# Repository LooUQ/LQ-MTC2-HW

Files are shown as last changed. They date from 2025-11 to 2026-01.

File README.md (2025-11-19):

# LooUQ MTC.2 Hardware

Welcome to the hardware and physical parts repository for the LooUQ MTC.2 Ecosystem. Here you will find resources to aid in your implementation of MTC.2 devices in your design/product. Many parts of the LooUQ MTC.2 ecosystem are available as open-source hardware and there design files are available here. There are also drawings for components that can be 3D printed. 

Software developement tooling is found in the LQ-MTC2-SW repository, which is also found on LooUQ's GitHub site.

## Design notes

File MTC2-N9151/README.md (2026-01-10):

# LooUQ MTC2-N9151

The LooUQ MTC2-N9151 is our flagship modem based on the Nordic Semiconductor nRF9151 System-in-Package (SIP) device. Nordic's [documentation](https://docs.nordicsemi.com/category/nrf9151-category) about the nRF9151 SIP is relevant the our MTC2-N9151 modem. LooUQ has done the work to package the nRF9151 SIP into a convenient PCB form to make incorporation into your device as straight forward as possible.

The [MTC.2 Interface Guide](https://drive.google.com/file/d/1XxZAA_1KvOwKZDBlQWn0SYPFL24nAV9U/view?usp=drive_link) discusses the steps to incorporate the N9151 into your product/project. 
* The physical characteristics of mounting the N9151 in your host system
* The electrical requirements needed by the N9151
* The signals to/from the N9151 and it's host

*LooUQ software developement tooling is found in the [LQ-MTC2-SW](https://github.com/LooUQ/LooUQ-MTC2-SW) repository (also found on LooUQ's GitHub site). This includes resources for Nordic Connect SDK like board definition files and sample applications.*

# What You Need
To work with the MTC2-N9151 you will need some things at hand.
* Microsoft [Visual Studio Code](https://code.visualstudio.com/) code editor
* Nordic's [Nordic NRF Connect](https://www.nordicsemi.com/Products/Development-tools/nRF-Connect-for-Desktop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) extension for VS Code
* Nordic's [nRF Connect for Desktop](https://www.nordicsemi.com/Products/Development-tools/nRF-Connect-for-Desktop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) (optional, but highly recommended)
* A SWD debugging probe (Segger J-Link recommended)
* A MTC.2 host providing connections and power (see LooUQ's offerings below, available in our online store)
* A MTC2-N9151 *(of course you will need one or more of these)*
* Antenna(s) 
    * Depending on your use case you will need a cellular antenna for LTE/DECT-NR+ and a GNSS antenna for GNSS/GPS location determination.

## Using LooUQ Development hosts
LooUQ has two development hosts available to make getting started with the MTC2-N9151 a straight forward process: the MTC2-N9151-BRK (breakout board) and the MTC2-N9151-UXP (UXplor host). With either of these two boards, you can get started developing applications for the N9151. They are physically the same size and have identical peripheral header pin configurations.

### MTC2-N9151-Breakout
The N9151 breakout board is simply that, a breakout, exposing all the signals to/from the MTC2-N9151 modem device. Connections for external power, nRF9151 reset, SWD (flash/debug) and all peripheral pins (GPIO, I2C, SPI, UART, etc.). The breakout is designed to be simple and stay out of the way, providing only the essentials for flashing and debugging your N9151 applications.

### MTC2-N9151-UXplor
The N9151 UXplor is the breakout PLUS handy other functionality. The UXplor has a USB connector that sources power via integrated regulators. There is a VDD regulator delivery 3.8v and a VIO regulator that can be set for 3.3v or 1.8v. There is also a RGB LED indicator, the RBG controller is from TI and is I2C-connected. LooUQ provides a driver for LED controller, which is available in the LooUQ-MTC2-SW software repository.

## Creating MTC2-N9151 Applications
If you are new to ***Nordic nRF Connect*** consider investing time in completing one or more of the fine online courses at the [Nordic Developer Academy](https://academy.nordicsemi.com/). If you already have nRF Connect development experience, head over to the [software repository](https://github.com/LooUQ/LooUQ-MTC2-SW) and check out the information there. We have board definitions, samples, and driver code ready for your use. 

## Creating Your Own MTC2-N9151 Host 
LooUQ uses DipTrace as our PCB design suite. It has a complete set of tools for schematic creation, PCB layout, and maintaining component libraries. For information about DipTrace and how to use it see...[Get Diptrace](https://diptrace.com/). LooUQ has been using DipTrace as our electronics design tool since 2016 and we are proud to proclaim it's virtues: reasonable cost, wide support, comprehensive set of tooling; give it a try.

Given that there are multiple tools out there for PCB design/develoment, LooUQ is sharing our open-hardware designs in both DipTrace and Eagle formats. Eagle is a widely supported format for schematic and PCB board layouts. Both of the host boards above are available in the Boards folder of this repository. Depending on your needs either could be a good starting point for integration into your project.

Nordic documentation about the nRF9151 SIP applies to the LooUQ MTC2-9151; all limits should be observed. The MTC2-N9151 will draw slightly more power depending on operating state. GNSS has power draw for either the on-board LNA chip and optionally the external LNA power injection circuit. The N9151 also has 2 LEDs (power-green, network-blue), which can be individually disabled by cutting a jumper. LooUQ can deliver the MTC2-N9151 with custom LNA or LED configurations (note MOQ is required).

### Interfacing to the N9151
* Physical layout
* Power
    * VDD: 3.0v - 5.5v (LooUQ has observed that when VDD is above 4.5v, a VIO of 1.8v has issues)
    * VIO: 1.7v to 3.6v
    * The UXplor VDD is 3.8v and VIO is selectable at 3.3v or 1.8v
* Flash/debug requires connectivity to the 2 SWD pins (both the Breakout and UXplor expose these signals to a 10-pin Cortex header)
* Both LTE/DECT and GNSS antennas are directly connected to the MTC2-N9151 via U.FL connectors

**Host Physical Board Layout**
The physical connection between the MTC2-N9151 and the host PCB is accomplished with 3 parts in the configuration below.
* TE 1-2199230-6 (M.2 Key-M)
* Wurth 9774025151R (M2.5 stand-off, soldered)
* 2.5M x 8mm hex head bolt (fully-threaded, course)

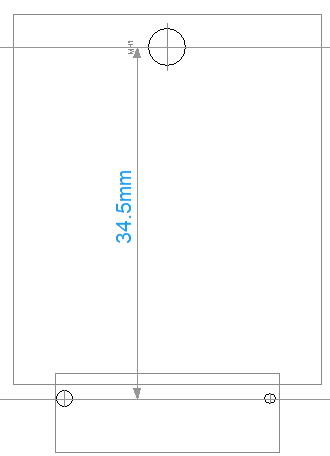
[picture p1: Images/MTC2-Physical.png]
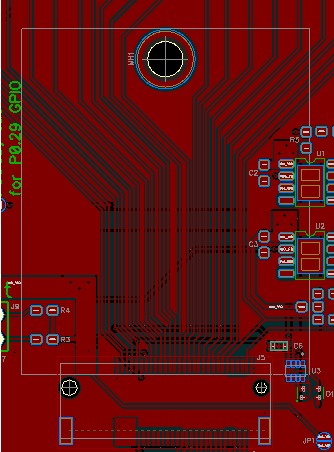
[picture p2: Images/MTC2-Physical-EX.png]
PCB


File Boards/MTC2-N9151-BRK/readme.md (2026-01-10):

# MTC2-N9151-BRK
The LooUQ MTC2-N9151 Breakout is a development board providing pin access to all of the MTC2-N9151 signals. It allows for software development, flashing and power monitoring via headers located along the right-hand side of the board. SWD access (debug/flashing) is via a standard 5x2 shrouded header.

The Breakout can also serve as a template for incorporating the MTC2-N9151 modem into your product design. Both DipTrace and Eagle design files are available here.

You can purchase ready-to-use Breakout boards from LooUQ at https://loouq.com/store.

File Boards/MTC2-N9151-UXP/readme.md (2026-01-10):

# MTC2-N9151-UXP
The LooUQ MTC2-N9151 UXplor is a development board providing pin access to all of the MTC2-N9151 signals. It allows for software development, flashing and power monitoring via headers located along the right-hand side of the board. SWD access (debug/flashing) is via a standard 5x2 shrouded header. The UXplor also provide N9151 board power from a USB connection. The VIO voltage can be selected via a jumper at either 3.3v or 1.8v (VDD is fixed at 3.7v). The UXplor also includes a RGB LED the is controlled via a TI constant current control chip on the host extension I2C interface.

You can obtain Zephyr devicetree overlays for the Host Extension interface in order to use the RGB LED with the LooUQ driver. These resources, including the driver, are found in the LooUQ GitHub at https://github.com/LooUQ/LooUQ-MTC2-SW.

You can purchase ready-to-use UXplor boards from LooUQ at https://loouq.com/store.

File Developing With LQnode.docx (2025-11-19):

# Developing With LQnode

Developing your sensor or actuator project with LQnode is a straightforward effort involving both creation of a “sensor” circuit and adding your C source code driver. Both efforts are supported by templates to facilitate a solid start and rapid completion.

# Hardware Circuit

## PCB Design Software

LQnode includes hardware templates and source materials to help you rapidly build your project. LooUQ provides these design resources (schematics and PC boards) in two formats: DipTrace and Eagle.

LooUQ uses DipTrace as our primary circuit CAD application. We selected it several years ago and have been pleased with its reasonable cost and solid features. DipTrace is available

Part of most LQnode projects is a custom circuit board (PCB) that is home to the electronics that make your sensor project unique; this could be actual sensors or more likely interface(s) to an external device or system. Beyond the interface itself, your hardware could also include specialized processing capabilities such as high-end computation power, extra memory, or a field programmable gate array (FPGA). This allows your project to utilize the LQnode platform for power and communications, while you focus on your core expertise to address a real-world need.

Start your hardware development with the LQnode-ANNEX PCB template. The template is available as a DipTrace or Eagle format board (https://github.com/LooUQ/LQnode-HW). The template has a board outline, connectors to the LQnode system board, and a placeholder group of prototyping pads. The prototyping connections can be kept or deleted as you see fit.

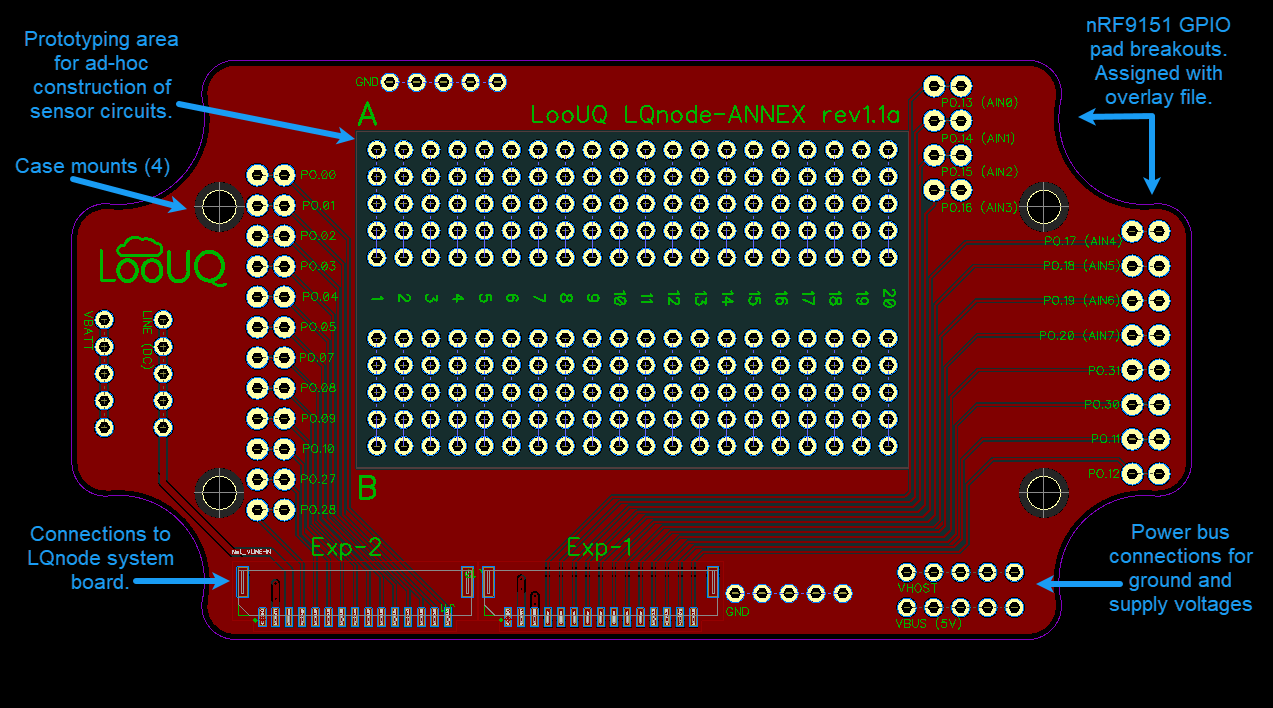
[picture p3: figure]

The only part on the prototype template PCB that is required are the two connectors to the LQnode system board. These are common JST BM15B-GHS-TBT(LF)(SN) connectors, you will also find compatible cables and plugs available from multiple sources. This connector has a latch mechanism to lock the connection cable in place.

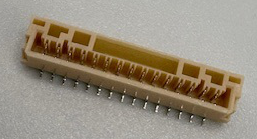
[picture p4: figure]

# Software Driver

As with hardware development, the best starting point is the LooUQ provided LQnode application template. LQnode software support files including demo applications/ templates and overlays, Zephyr port mappings for Nordic Connect SDK, are available in the https://github.com/LooUQ/LQnode-SW GitHub repository.

# Licensing

LooUQ has expended time and money developing the LQnode system for rapid development of IoT device applications. We want its capabilities to be put to work addressing real world needs both for good of all and for profit.

All LQnode components, hardware and software, are available under the Polyform Noncommercial (https://polyformproject.org/licenses/noncommercial/1.0.0/) license for non-commercial projects. Polyform Noncommercial is a source-available license, rather than an open-source license. The full source code and component drawings are available for your use, under the license conditions.

Individuals, academic institutions, and non-profit organizations are encouraged to freely use the LQnode system for your project.

Commercial use of LQnode requires a commercial use license that can be obtained from LooUQ. To inquire about pricing and availability of a license compatible with your project please reach out, we are eager to work with you to provide reasonable terms. Licensing inquiries can be directed to answers@loouq.com, we will respond as soon as possible to start working on ways we can work together for mutual benefit.

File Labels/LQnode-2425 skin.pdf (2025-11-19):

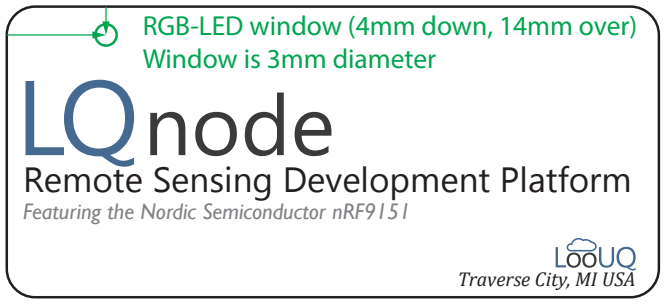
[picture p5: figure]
node; Remote Sensing Development Platform; Traverse City, MI USA; Featuring the Nordic Semiconductor nRF9151; RGB-LED window (4mm down, 14mm over) Window is 3mm diameter

Die-cut outline above: 92mm x 41mm, 4mm rounded corners

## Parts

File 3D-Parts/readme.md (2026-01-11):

## LQnode 3D Printable Parts

This folder contains STL files for enclosure accessories. The parts here are all available open-source, so print away. They also 
can be purchased from the LooUQ Store if that is more convenient [LQstore](https://loouq.com/store).

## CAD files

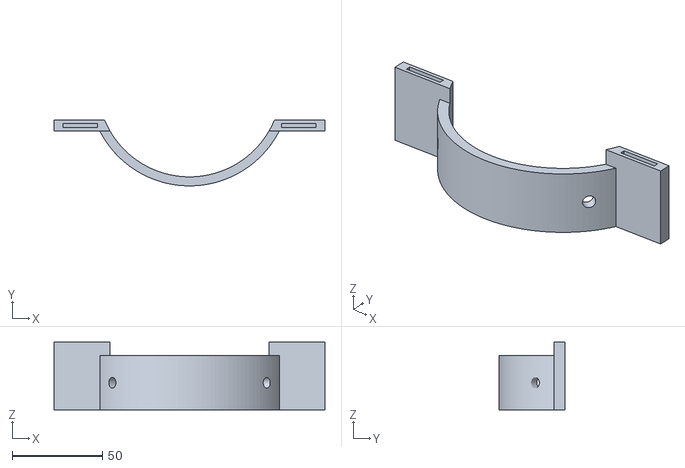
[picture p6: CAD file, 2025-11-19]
3D-Parts/lqnode_ventAdptr4.stl
150.0 x 36.4 x 37.5

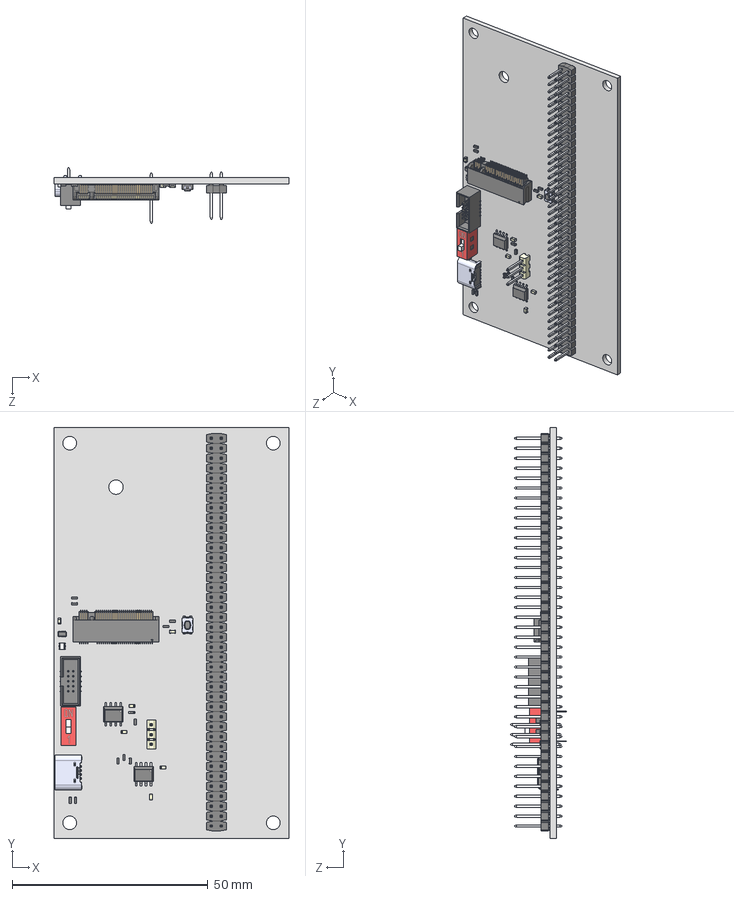
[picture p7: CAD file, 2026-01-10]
Boards/MTC2-N9151-UXP/MTC2-N9151-UXP rev2-2a.step
60.0 x 105.0 x 14.2 mm
Board_mtc2-n9151-uxplor_rev2-2a
cap_0603 x 5
CL10B105KP8NNNC
Everlight--EAST1616RGBB4
CNC-3220-10-0300-00
TE_1-2199230-6
GCT__USB4125-GF-A-0190
hdr-2x40t_2.54x2.54_102x5
hdr-1x3t_2.54_7x2
res_0603 x 11
C&K-KMR231GLFS
Wurth_418117270901
soic-8ep_150mil x 2
TI--LP5817DRLR

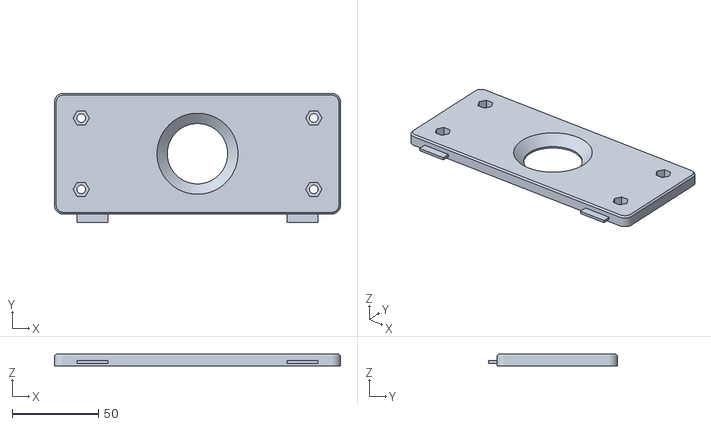
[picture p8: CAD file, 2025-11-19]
3D-Parts/lqnode_backPlate.stl
166.0 x 75.0 x 7.00

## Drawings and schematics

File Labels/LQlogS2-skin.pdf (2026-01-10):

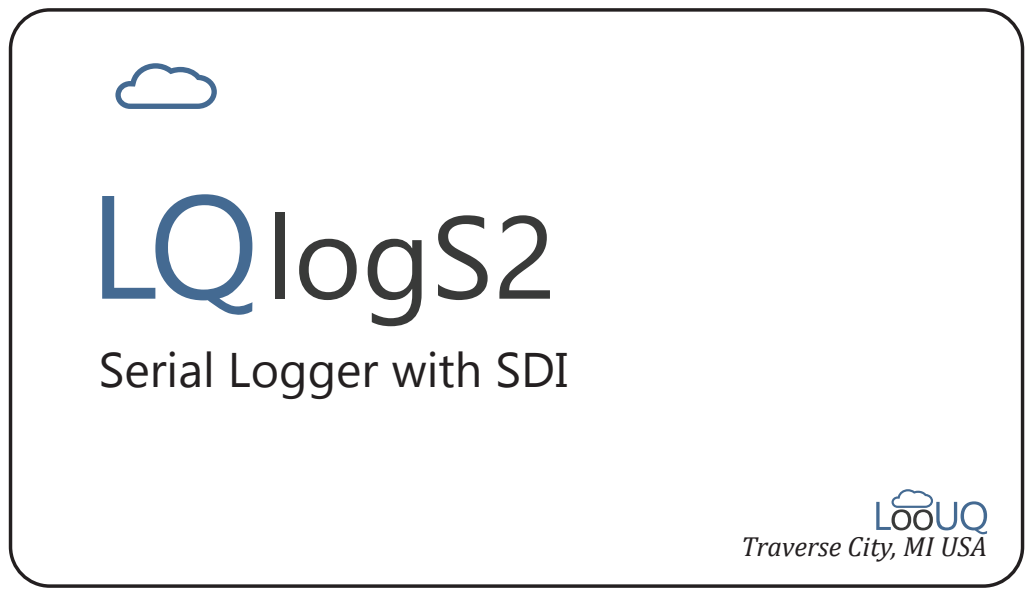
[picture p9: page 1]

RGB-LED window (8.1mm down, 15.4mm over)
Window is 3mm diameter
logS2

Serial Logger with SDI

Traverse City, MI USA

Die-cut outline above: 103mm x 58mm, 4mm rounded corners

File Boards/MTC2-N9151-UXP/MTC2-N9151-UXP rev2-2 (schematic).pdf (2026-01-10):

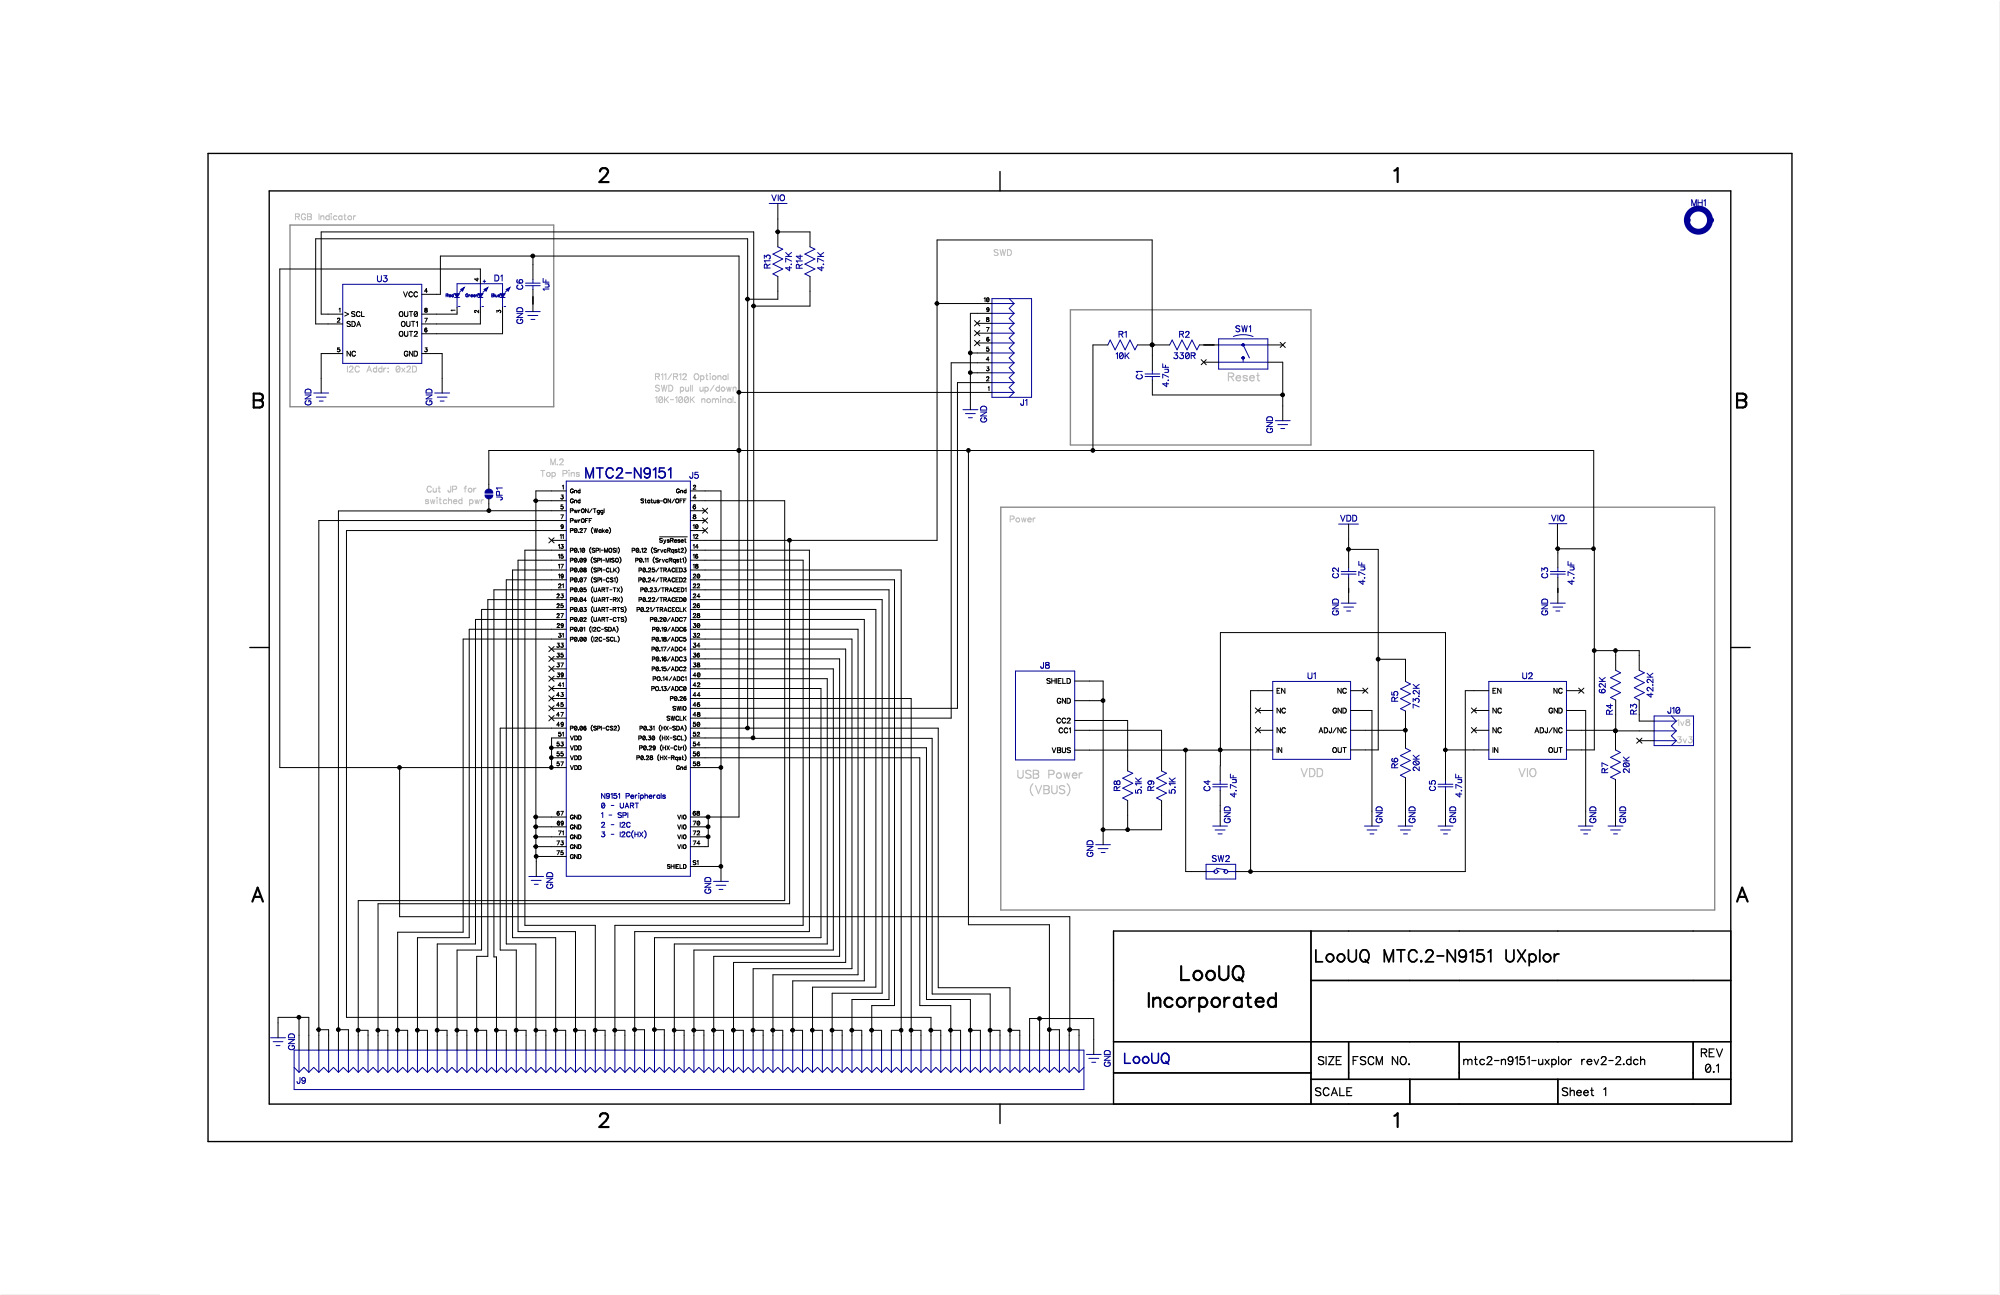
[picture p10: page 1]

R11/R12 Optional
SWD pull up/down
10K-100K nominal.

PwrON/Tggl 5 | 6
PwrOFF 7 | 8
9 | | 10
11 | | 14 16 18 20 22 24 28 30 32 34

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
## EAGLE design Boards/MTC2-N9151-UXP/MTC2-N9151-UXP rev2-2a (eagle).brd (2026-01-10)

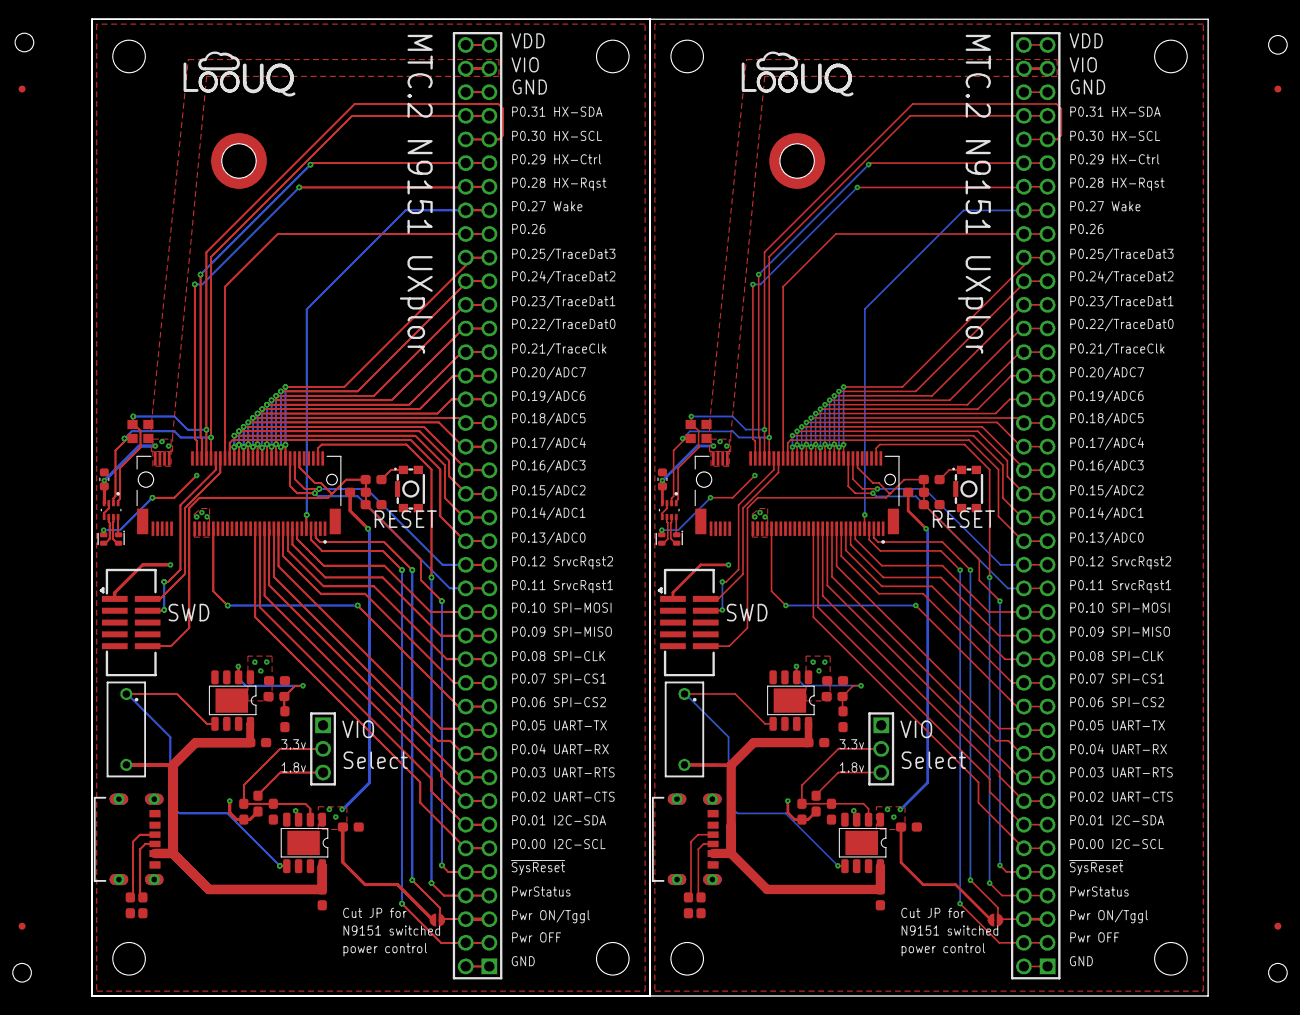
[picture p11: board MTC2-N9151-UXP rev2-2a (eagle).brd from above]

Board: 2 copper layers, 120.0 x 105.0 mm, 66 parts (0 on the bottom side), 52 nets.

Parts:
C1_1_1, C1_2_1, C2_1_1, C2_2_1, C3_1_1, C3_2_1, C4_1_1, C4_2_1: 4.7uF; CAP_0603
C5_1_1, C5_2_1: 4.7uF; CAP_0603_C5
C6_1_1, C6_2_1: 1uF; CAP_0603_N
D1_1_1, D1_2_1: EAST1616RGBB4; EAST1616RGBB2
FID1, FID2, FID3, FID4: FIDUCIAL; Fiducial
J1_1_1, J1_2_1: CNCTECH 3220-10-0300-00-TR; CnCTech_3220-10-0300-00-TR
J5_1_1, J5_2_1: MTC.2 1-2199230-6 (N9151); TE_1-2199230-6
J8_1_1, J8_2_1: USB4125-GF-A-0190; GCT_USB4125-GF-A-0190_REVA2
J9_1_1, J9_2_1: 90131-0160; HDR-2x40T/2.54x2.54/102x5
J10_1_1, J10_2_1: HDR-1X3T/2.54; HDR-1x3T/2.54/7x2
JP1_1_1, JP1_2_1: CIRCJUMPER-2; Circ-Jumper-2
LG1_1_1, LG1_2_1: LOOUQ LOGO; LooUQ-6mm
MH1_1_1, MH1_2_1: 9774025151R; m.2_standoff
R1_1_1, R1_2_1: 10K; RES_0603
R2_1_1, R2_2_1: 330R; RES_0603_R2
R3_1_1, R3_2_1: 41.7K; RES_0603_R3
R4_1_1, R4_2_1: 62K; RES_0603_R2
R5_1_1, R5_2_1: 73.2K; RES_0603_R5
R6_1_1, R6_2_1: 20K; RES_0603_R6
R7_1_1, R7_2_1: 20K; RES_0603_R5
R8_1_1, R8_2_1, R9_1_1, R9_2_1: 5.1K; RES_0603_R8
R13_1_1, R13_2_1, R14_1_1, R14_2_1: 4.7K; RES_0603_R13
SW1_1_1, SW1_2_1: KMR221GLFS; KMR-2-wG
SW2_1_1, SW2_2_1: 418117270901
U1_1_1, U1_2_1, U2_1_1, U2_2_1: AP7361EA-SPR-13; SO-8EP
U3_1_1, U3_2_1: LP5817DRLR; IC_LP5817DRLR

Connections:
ND_RESETSW: R2_1_1.2, R2_2_1.2, SW1_1_1.1@, SW1_1_1.1@_1, SW1_2_1.1@, SW1_2_1.1@_1
Net_52: J10_1_1.3, J10_2_1.3, R3_1_1.1, R3_2_1.1
Net_Blue: D1_1_1.3, D1_2_1.3, U3_1_1.6, U3_2_1.6
Net_GND: C1_1_1.1, C1_2_1.1, C2_1_1.1, C2_2_1.1, C3_1_1.1, C3_2_1.1, C4_1_1.1, C4_2_1.1, C5_1_1.1, C5_2_1.1, C6_1_1.1, C6_2_1.1, J1_1_1.3, J1_1_1.5, J1_1_1.9, J1_2_1.3, J1_2_1.5, J1_2_1.9, J5_1_1.1, J5_1_1.2, J5_1_1.3, J5_1_1.58, J5_1_1.67, J5_1_1.69, J5_1_1.71, J5_1_1.73, J5_1_1.75, J5_1_1.S1, J5_1_1.S2, J5_2_1.1, J5_2_1.2, J5_2_1.3, J5_2_1.58, J5_2_1.67, J5_2_1.69, J5_2_1.71, J5_2_1.73, J5_2_1.75, J5_2_1.S1, J5_2_1.S2, J8_1_1.A12, J8_1_1.S1, J8_1_1.S2, J8_1_1.S3, J8_1_1.S4, J8_2_1.A12, J8_2_1.S1, J8_2_1.S2, J8_2_1.S3, J8_2_1.S4, J9_1_1.1, J9_1_1.2, J9_1_1.75, J9_1_1.76, J9_2_1.1, J9_2_1.2, J9_2_1.75, J9_2_1.76, R6_1_1.2, R6_2_1.2, R7_1_1.1, R7_2_1.1, R8_1_1.1, R8_2_1.1, R9_1_1.1, R9_2_1.1, SW1_1_1.2@, SW1_1_1.2@_1, SW1_2_1.2@, SW1_2_1.2@_1, U1_1_1.3, U1_2_1.3, U2_1_1.3, U2_2_1.3, U3_1_1.3, U3_1_1.5, U3_2_1.3, U3_2_1.5
Net_Green: D1_1_1.2, D1_2_1.2, U3_1_1.7, U3_2_1.7
Net_PWR-TGL: J5_1_1.5, J5_2_1.5, J9_1_1.5, J9_1_1.6, J9_2_1.5, J9_2_1.6, JP1_1_1.1, JP1_2_1.1
Net_PwrEn: SW2_1_1.1, SW2_2_1.1, U1_1_1.5, U1_2_1.5, U2_1_1.5, U2_2_1.5
Net_Red: D1_1_1.1, D1_2_1.1, U3_1_1.8, U3_2_1.8
Net_SWCLK: J1_1_1.4, J1_2_1.4, J5_1_1.48, J5_2_1.48
Net_SWIO: J1_1_1.2, J1_2_1.2, J5_1_1.46, J5_2_1.46
Net_VBUS: C4_1_1.2, C4_2_1.2, C5_1_1.2, C5_2_1.2, J8_1_1.A9, J8_2_1.A9, SW2_1_1.A1, SW2_2_1.A1, U1_1_1.8, U1_2_1.8, U2_1_1.8, U2_2_1.8
Net_VDD: C2_1_1.2, C2_2_1.2, D1_1_1.4, D1_2_1.4, J5_1_1.51, J5_1_1.53, J5_1_1.55, J5_1_1.57, J5_2_1.51, J5_2_1.53, J5_2_1.55, J5_2_1.57, J9_1_1.79, J9_1_1.80, J9_2_1.79, J9_2_1.80, R5_1_1.2, R5_2_1.2, U1_1_1.1, U1_2_1.1
Net_VIO: C3_1_1.2, C3_2_1.2, C6_1_1.2, C6_2_1.2, J1_1_1.1, J1_2_1.1, J5_1_1.68, J5_1_1.70, J5_1_1.72, J5_1_1.74, J5_2_1.68, J5_2_1.70, J5_2_1.72, J5_2_1.74, J9_1_1.77, J9_1_1.78, J9_2_1.77, J9_2_1.78, JP1_1_1.2, JP1_2_1.2, R1_1_1.2, R1_2_1.2, R3_1_1.2, R3_2_1.2, R4_1_1.2, R4_2_1.2, R13_1_1.2, R13_2_1.2, R14_1_1.2, R14_2_1.2, U2_1_1.1, U2_2_1.1, U3_1_1.4, U3_2_1.4
P0.01_(I2C-SCL): J5_1_1.31, J5_2_1.31, J9_1_1.11, J9_1_1.12, J9_2_1.11, J9_2_1.12
P0.01_(I2C-SDA): J5_1_1.29, J5_2_1.29, J9_1_1.13, J9_1_1.14, J9_2_1.13, J9_2_1.14
P0.02_(UART-CTS): J5_1_1.27, J5_2_1.27, J9_1_1.15, J9_1_1.16, J9_2_1.15, J9_2_1.16
P0.03_(UART-RTS): J5_1_1.25, J5_2_1.25, J9_1_1.17, J9_1_1.18, J9_2_1.17, J9_2_1.18
P0.04_(UART-RX): J5_1_1.23, J5_2_1.23, J9_1_1.19, J9_1_1.20, J9_2_1.19, J9_2_1.20
P0.05_(UART-TX): J5_1_1.21, J5_2_1.21, J9_1_1.21, J9_1_1.22, J9_2_1.21, J9_2_1.22
P0.06_(SPI-CS2): J5_1_1.49, J5_2_1.49, J9_1_1.23, J9_1_1.24, J9_2_1.23, J9_2_1.24
P0.07_(SPI-CS1): J5_1_1.19, J5_2_1.19, J9_1_1.25, J9_1_1.26, J9_2_1.25, J9_2_1.26
P0.08_(SPI-CLK): J5_1_1.17, J5_2_1.17, J9_1_1.27, J9_1_1.28, J9_2_1.27, J9_2_1.28
P0.09_(SPI-MISO): J5_1_1.15, J5_2_1.15, J9_1_1.29, J9_1_1.30, J9_2_1.29, J9_2_1.30
P0.10_(SPI-MOSI): J5_1_1.13, J5_2_1.13, J9_1_1.31, J9_1_1.32, J9_2_1.31, J9_2_1.32
P0.11_(nSrvcRqst1): J5_1_1.16, J5_2_1.16, J9_1_1.33, J9_1_1.34, J9_2_1.33, J9_2_1.34
P0.12_(nSrvcRqst2): J5_1_1.14, J5_2_1.14, J9_1_1.35, J9_1_1.36, J9_2_1.35, J9_2_1.36
P0.13/ADC0: J5_1_1.42, J5_2_1.42, J9_1_1.37, J9_1_1.38, J9_2_1.37, J9_2_1.38
P0.14/ADC1: J5_1_1.40, J5_2_1.40, J9_1_1.39, J9_1_1.40, J9_2_1.39, J9_2_1.40
P0.15/ADC2: J5_1_1.38, J5_2_1.38, J9_1_1.41, J9_1_1.42, J9_2_1.41, J9_2_1.42
P0.16/ADC3: J5_1_1.36, J5_2_1.36, J9_1_1.43, J9_1_1.44, J9_2_1.43, J9_2_1.44
P0.17/ADC4: J5_1_1.34, J5_2_1.34, J9_1_1.45, J9_1_1.46, J9_2_1.45, J9_2_1.46
P0.18/ADC5: J5_1_1.32, J5_2_1.32, J9_1_1.47, J9_1_1.48, J9_2_1.47, J9_2_1.48
P0.19/ADC6: J5_1_1.30, J5_2_1.30, J9_1_1.49, J9_1_1.50, J9_2_1.49, J9_2_1.50
P0.20/ADC7: J5_1_1.28, J5_2_1.28, J9_1_1.51, J9_1_1.52, J9_2_1.51, J9_2_1.52
P0.21/TRACECLK: J5_1_1.26, J5_2_1.26, J9_1_1.53, J9_1_1.54, J9_2_1.53, J9_2_1.54
P0.22/TRACED0: J5_1_1.24, J5_2_1.24, J9_1_1.55, J9_1_1.56, J9_2_1.55, J9_2_1.56
P0.23/TRACED1: J5_1_1.22, J5_2_1.22, J9_1_1.57, J9_1_1.58, J9_2_1.57, J9_2_1.58
P0.24/TRACED2: J5_1_1.20, J5_2_1.20, J9_1_1.59, J9_1_1.60, J9_2_1.59, J9_2_1.60
P0.25/TRACED3: J5_1_1.18, J5_2_1.18, J9_1_1.61, J9_1_1.62, J9_2_1.61, J9_2_1.62
P0.26: J5_1_1.44, J5_2_1.44, J9_1_1.63, J9_1_1.64, J9_2_1.63, J9_2_1.64
P0.27_(Wake): J5_1_1.9, J5_2_1.9, J9_1_1.65, J9_1_1.66, J9_2_1.65, J9_2_1.66
P0.28_(HX-RQST): J5_1_1.56, J5_2_1.56, J9_1_1.67, J9_1_1.68, J9_2_1.67, J9_2_1.68
P0.29_(HX-Ctrl): J5_1_1.54, J5_2_1.54, J9_1_1.69, J9_1_1.70, J9_2_1.69, J9_2_1.70
P0.30_HX-SCL: J5_1_1.52, J5_2_1.52, J9_1_1.71, J9_1_1.72, J9_2_1.71, J9_2_1.72, R14_1_1.1, R14_2_1.1, U3_1_1.1, U3_2_1.1
P0.31_HX-SDA: J5_1_1.50, J5_2_1.50, J9_1_1.73, J9_1_1.74, J9_2_1.73, J9_2_1.74, R13_1_1.1, R13_2_1.1, U3_1_1.2, U3_2_1.2
PUSB_CC1: J8_1_1.A5, J8_2_1.A5, R9_1_1.2, R9_2_1.2
PUSB_CC2: J8_1_1.B5, J8_2_1.B5, R8_1_1.2, R8_2_1.2
PWR-OFF: J5_1_1.7, J5_2_1.7, J9_1_1.3, J9_1_1.4, J9_2_1.3, J9_2_1.4
Status-ON/OFF: J5_1_1.4, J5_2_1.4, J9_1_1.7, J9_1_1.8, J9_2_1.7, J9_2_1.8
VDD_FB: R5_1_1.1, R5_2_1.1, R6_1_1.1, R6_2_1.1, U1_1_1.2, U1_2_1.2
VIO_FB: J10_1_1.2, J10_2_1.2, R4_1_1.1, R4_2_1.1, R7_1_1.2, R7_2_1.2, U2_1_1.2, U2_2_1.2
nSysReset: C1_1_1.2, C1_2_1.2, J1_1_1.10, J1_2_1.10, J5_1_1.12, J5_2_1.12, J9_1_1.9, J9_1_1.10, J9_2_1.9, J9_2_1.10, R1_1_1.1, R1_2_1.1, R2_1_1.1, R2_2_1.1

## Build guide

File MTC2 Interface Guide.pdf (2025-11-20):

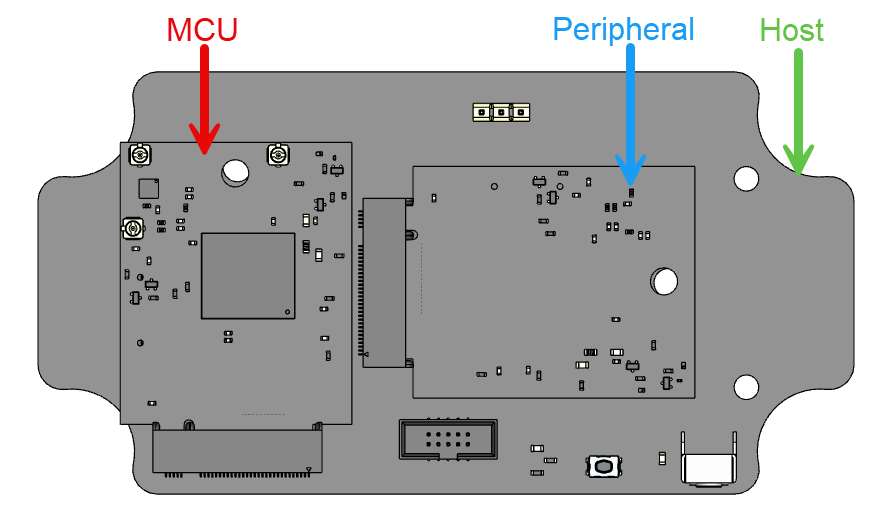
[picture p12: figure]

Copyright 2025 LooUQ Incorporated
License: MIT | Page 1 | Rev. 1.0 - 7/21/2025

# LooUQ MTC.2 Interface

The LooUQ MTC.2 Interface is designed to support peripheral device to host communications for many dierent types of peripherals. Initially, the MTC.2 interface is being used by LooUQ for connectivity between our MTC.2 compatible modems (LTE communications) and host boards (PCB) for system capabilities including power, user input, indication, and sensors.
This specification is really intended to serve as a convention, defining known locations for typical inter-connect signals: power, grounds, GPIO and serial communications.
The connection between the master device and the peripheral is via an M.2 type card-edge connector. The peripheral side has card-edge finger contacts; the host has an connector (TE 1-2199230-6).
As shown below, there are 3 possible participants in a system containing MTC.2 interfaces. There are the Host, the MCU, and the Peripheral. Not all these three roles may be as configured below; for example, the MCU function may be resident directly on the Host board.

The fact that an MTC.2 device can be either an MCU, a Peripheral or both (a subsystem. peripheral with an MCU) can complicate the description of signal sources and the direction of the signal. In this document, the term “DEVICE” refers to the PCB plugged into the TE connector (both the MCU and the Peripheral in the drawing below are a DEVICE).
Host Typically provides power and physical connectivity, can also provide user interaction with displays and/or buttons.

License: MIT | Page 2 | Rev. 1.0 - 7/21/2025

MCU

The primary system processor, generally the device running the embedded application firmware. It can include other functions like the LooUQ N9151 that has both MCU (processor, memory, etc.) and cellular communications.

Peripheral

An MTC.2 connected board performing the duties of a sub-system. This may be a board with MCU running sub-system firmware. Typical types of smart peripherals (with MCU) could be additional communication stacks, dedicated numeric processing for intensive tasks, or specialized I/O.

### MTC2-N9151

- Devices like the MTC2-N9151 can act as either master or slave for serial peripherals like SPI and I2C; for these two serial functions, the direction is in relation to the MASTER configured device.
For UART applications the Zephyr UART by default acts like in the DTE (data terminal equipment) role, which sources the TX and RTS signals. If your application requires it to be set up as a DCE, you will need to adjust the device tree (for Zephyr) or host wiring much like a null-modem cable.

# MTC.2 Signals

### Top Edge of MTC.2 Card

Signal Name | M.2 Pin | Direction | Comments | N9151
Ground | 1 3 | | Power Ground
Power Toggle/ON | 5 | Input to MCU | Logic signal to turn on or in some cases toggle power state of the MCU
N.C. | 7
Wake | 9 | Input to MCU | Logic signal to wake MCU from sleep state | P0.27
N.C. | 11
SPI-MOSI | 13 | From SPI Master | | P0.10
SPI-MISO | 15 | To SPI Master | | P0.09
SPI-CLK | 17 | From SPI Master | | P0.08
SPI-CS | 19 | From SPI Master | This is the default CS, preconfigured for CS on SPI for the N9151 | P0.07
UART0-TX | 21 | From DEVICE | Data output from UART | P0.05
UART0-RX | 23 | To DEVICE | Data input to UART | P0.04
UART0-RTS | 25 | From DEVICE | Asserted when sending, listening to CTS | P0.03
UART0-CTS | 27 | To DEVICE | Asserted when able to receive | P0.02
I2C-SDA | 29 | Bi-directional | Shared across all I2C bus devices as SDA and SCL | P0.01
I2C-SCL | 31 | | | P0.00
N.C. User-Defined | 33
| 35

License: MIT | Page 3 | Rev. 1.0 - 7/21/2025
37 User-defined signals. LooUQ will not | assign to any function in our commercial designs.
39
41
43
45
47
Power Good | 49 | Input to MCU | Input to MCU from Host indicating power source is good/operational | P0.06
VBus (5.0v) | 51 | To MTC.2 Device | Usually supplied by the Host board to both MCU and Peripheral devices.
53
55
57
Key Slot
VBatt | 67 | To MTC.2 Device

Usually supplied by the Host board 69 to both MCU and Peripheral devices.
| 71
| 73
Ground | 75

### Bottom Edge of MTC.2 Card

Signal Name | M.2 Pin | Direction | Comments | N9151
Ground | 2 | System Ground
Status-ON/OFF | 4
N.C. | 6
N.C. | 8
N.C. | 10
nReset | 12 | To MTC.2 Device | Reset MCU or Peripheral (Active Low)
nSrvcRqst | 14 | To MCU | Service Request (Active Low) Assigned to IRQ | P0.12
nSrvcPend | 16 | To MCU | Service Pending (Active Low) Held low until request serviced | P0.11
GPIO | 18 | | Trace Data[3] | P0.25
GPIO | 20 | | Trace Data[2] | P0.24
GPIO | 22 | | Trace Data[1] | P0.23
GPIO | 24 | | Trace Data[0] | P0.22
GPIO | 26 | | Trace Clock | P0.21
GPIO | 28 | | ADC7 | P0.20
GPIO | 30 | | ADC6 | P0.19
GPIO | 32 | | ADC5 | P0.18
GPIO | 34 | | ADC4 | P0.17
GPIO | 36 | | ADC3 | P0.16
GPIO | 38 | | ADC2 | P0.15
GPIO | 40 | | ADC1 | P0.14
GPIO | 42 | | ADC0 | P0.13

License: MIT | Page 4 | Rev. 1.0 - 7/21/2025
GPIO/HX-CS1 | 44 | | GPIO designated for HX alternate CS | P0.26
SWD-IO | 46 | To MCU with SWD connector on host | SWD debugger interface SWD-CLK
| 48
HX-MOSI | 50 | From SPI Master | The HX (host extension) interface is intended to assist with multiple MTC.2 peripheral systems and use of external multiplexor components. | P0.31
HX-MISO | 52 | To SPI Master | | P0.30
HX-CLK | 54 | From SPI Master | | P0.29
HX-CS0 | 56 | From SPI Master | | P0.28
Ground | 58 | System Ground
Key Slot

VHost

### 68 Supply that is usually provided by the Host board. This

supply sets the logic voltage for all devices in a system. Range supported 1.8v to 3.3v.

70
72
74

This interface specification is copyright LooUQ Incorporated and license under the MIT open-source license.
THE SOFTWARE IS PROVIDED “AS IS”, WITHOUT WARRANTY OF ANY KIND, EXPRESS OR IMPLIED, INCLUDING BUT NOT LIMITED TO THE WARRANTIES OF MERCHANTABILITY, FITNESS FOR A PARTICULAR PURPOSE AND NONINFRINGEMENT. IN NO EVENT SHALL THE AUTHORS OR COPYRIGHT HOLDERS BE LIABLE FOR ANY CLAIM, DAMAGES OR OTHER LIABILITY, WHETHER IN AN ACTION OF CONTRACT, TORT OR OTHERWISE, ARISING FROM, OUT OF OR IN CONNECTION WITH THE SOFTWARE OR THE USE OR OTHER DEALINGS IN THE SOFTWARE.

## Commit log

2025-11-19 Update from local
    [lqnode_backPlate.stl, lqnode_ventAdptr4.stl, pcbBenchStand-24_25.stl]
2025-11-19 Added N9151-BRK files
    [mtc2-n9151-breakout_EAGLE.brd, mtc2-n9151-breakout_EAGLE.sch, mtc2-n9151-breakout_PCAD.sch]
2025-11-20 Add implementation resources
    [MTC2-Template.brd, mtc2-n9151-breakout.brd, mtc2-n9151-breakout.sch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]
2025-11-22 Update readme and reorganize hw locations
    [mtc2-n9151-breakout.brd, mtc2-n9151-breakout.sch, mtc2-n9151-brk rev2-0 BOM.csv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]
2026-01-10 Updated BRK and UXP board files
    [MTC2-N9151-BRK rev2-2 (Eagle).sch, MTC2-N9151-BRK rev2-2a (Eagle).brd, MTC2-N9151-UXP rev2-2a (eagle).brd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]
